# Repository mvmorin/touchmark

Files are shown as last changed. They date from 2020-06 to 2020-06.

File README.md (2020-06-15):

# Touchmark
One-piece split, staggered column 40% keyboard. First prototyped on, and inspired by, the [Signum 3.0](http://troyfletcher.net/keyboard_sales.html#signum_30). Low profile and case-less yet still robust enough for travel. Designed in KiCad with symbols and footprints from [keyboard-parts](https://github.com/mvmorin/keyboard-parts) library.

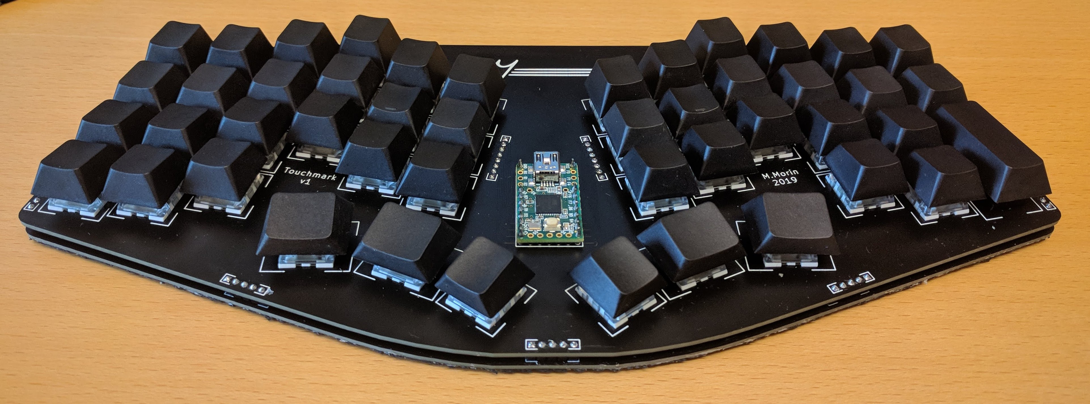
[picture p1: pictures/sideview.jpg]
sideview

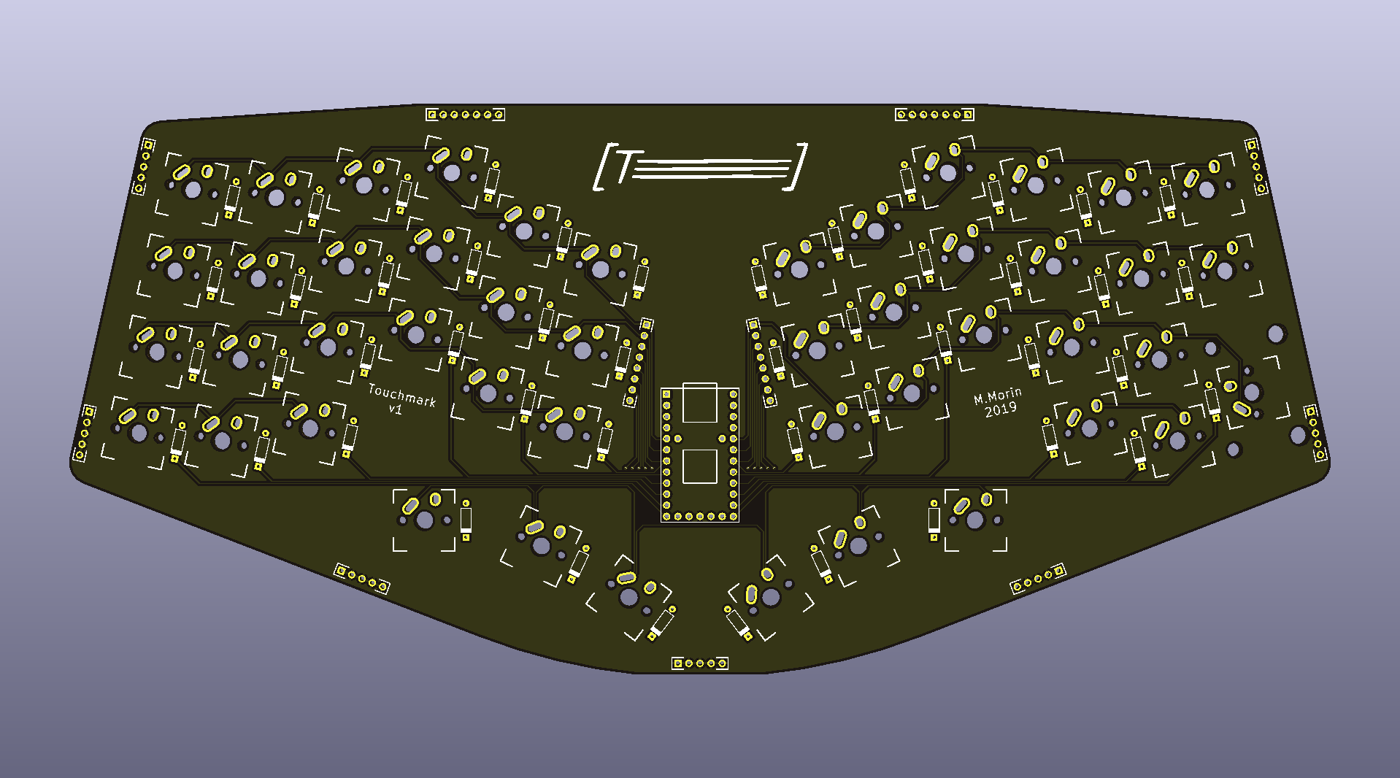
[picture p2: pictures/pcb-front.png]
pcb-front


# Features
* Low profile and case-less.
* Standard 4x12 layout.
* Teensy 2.0 and Pro-Micro compatible.
* Full PCB design, including backplate.
* Dedicated MX and Alps plates.
* Flat bottom makes it possible to use it directly on top of a laptop keyboard.

# Construction
The PCB and plate are connected via the switches and standard 2.54 mm pin headers. The Teensy/ProMicro is mounted on the plate itself (or on the base PCB if no plate is used). Only through-hole soldering is necessary and all components are placed on the top of the PCB, leaving the bottom of the keyboard flat. It is recommended to cover the bottom with some soft rubber-like material, I glued on some black shelf liner. It is of course possible to use small rubber feet instead, but this will leave the PCB exposed. It also makes it harder to use on top of a laptop keyboard since the bottom then isn't completely flat.

# PCB Files
The gerber-files for the latest version of the base PCB and the plates are found in the *gerber* directory. For instructions on how to order, see the following [40percent.club](http://www.40percent.club/2017/03/ordering-pcb.html) post. However, please read the **Known Issues** section below and be aware that the tolerances of PCB milling can be large.

# Known Issues
* Alps cutouts are a little tight. About 60% of the cutouts in the test print needed filing.
* Cherry stabilizer cutout are tight but usable.

# Future Updates
Things I'm currently thinking about changing, but who knows when...
* Change from row-high to row-low matrix for easier matrix scan in [tmk](https://github.com/tmk/tmk_keyboard) and to avoid turning on the LED when pressing column 12 keys.
* Increased stagger for pinky keys.
* Change split angle, currently slightly uncomfortable for me. The change of pinky-stagger will probably require a change to the split.
* Remove unused keys on bottom row (2,3,10,11).
* Move thumb clusters up.

# Licenses


This project is released under the [Creative Commons CC-BY-SA 4.0](https://creativecommons.org/licenses/by-sa/4.0/legalcode) license, Copyright (c) Martin Morin 2020.
Some footprints and symbols are based on parts from the [KiCad libraries](https://kicad-pcb.org/libraries/), released under the same [CC-BY-SA 4.0](https://creativecommons.org/licenses/by-sa/4.0/legalcode) license.

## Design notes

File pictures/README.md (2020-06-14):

# Pictures and Renders
sideview
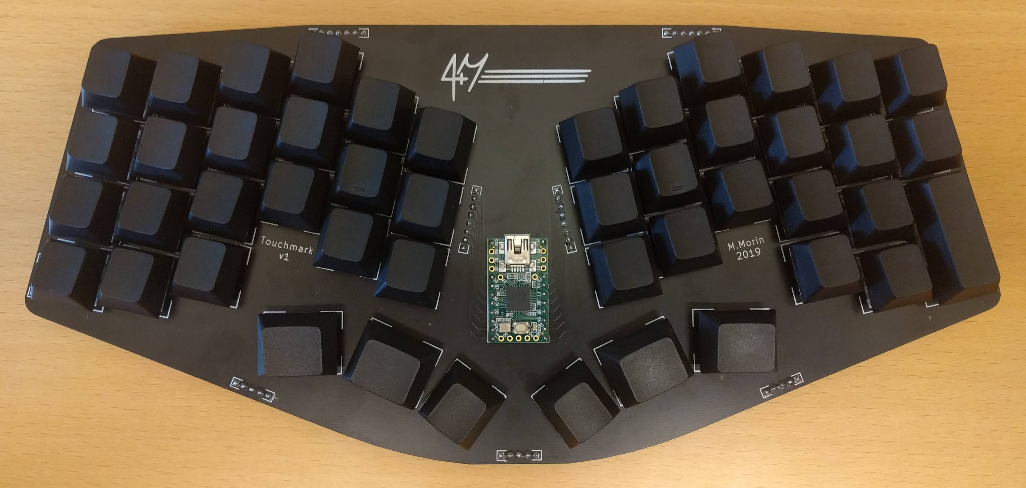
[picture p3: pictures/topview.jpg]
topview

## PCB Front and Back
pcb-front
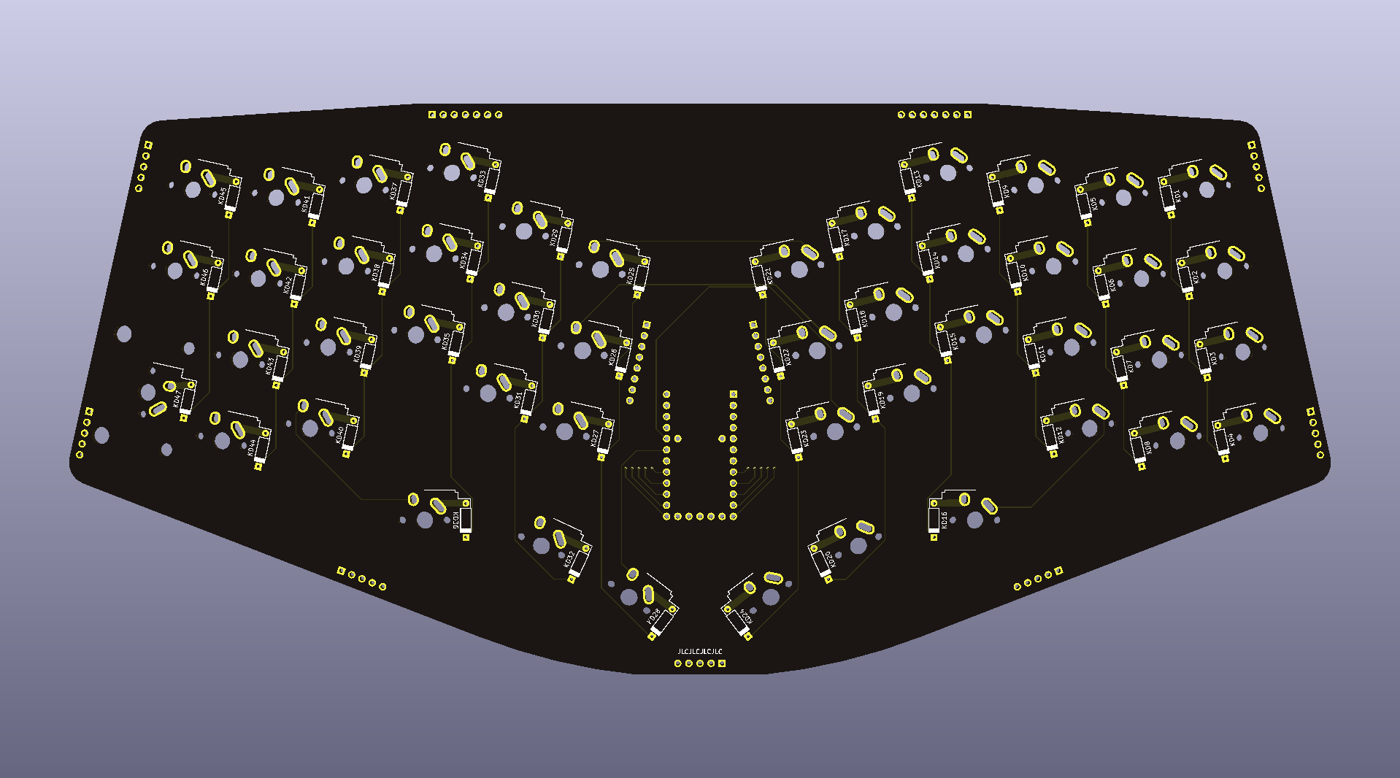
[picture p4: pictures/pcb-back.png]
pcb-back

## MX Plate
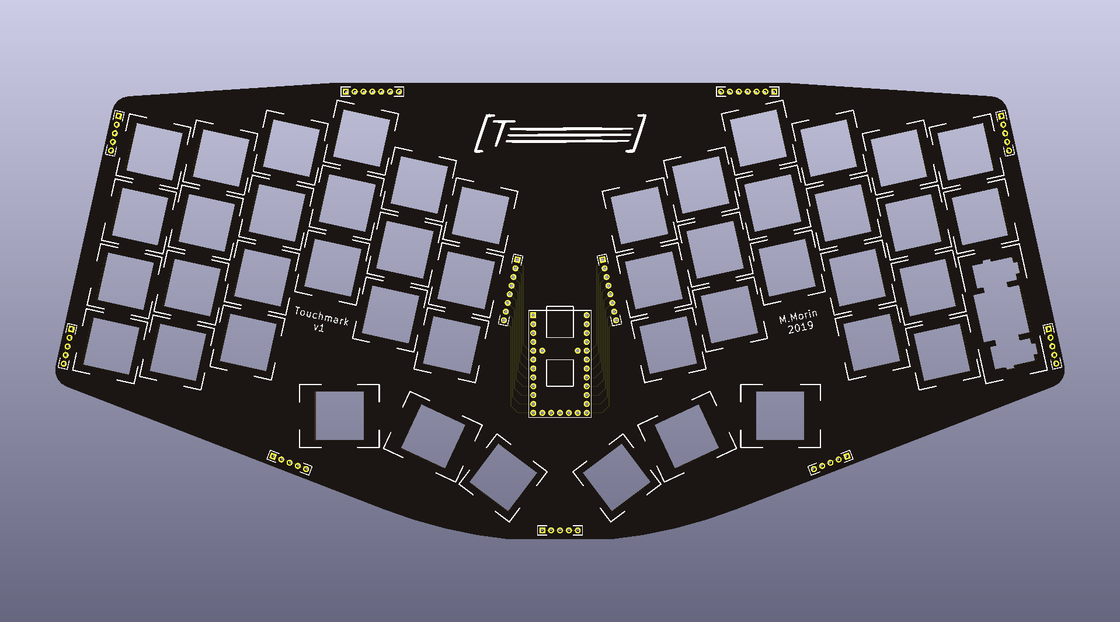
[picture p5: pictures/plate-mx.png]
plate-mx

## Alps Plate
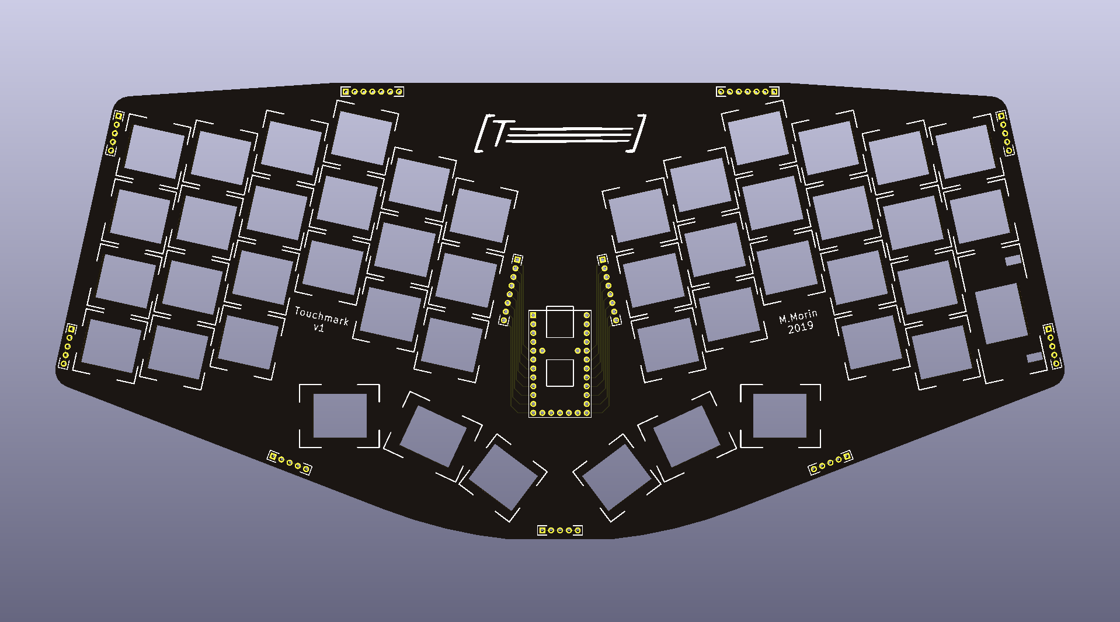
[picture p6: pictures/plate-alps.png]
plate-alps


Note the change of logo since the test print.

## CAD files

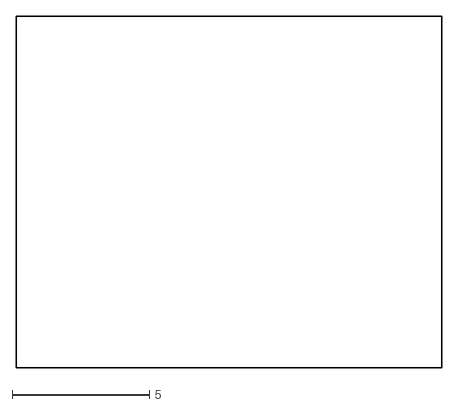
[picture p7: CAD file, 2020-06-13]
keyboard-parts/plate-cutouts/alps_cutout.dxf
15.5 x 12.8

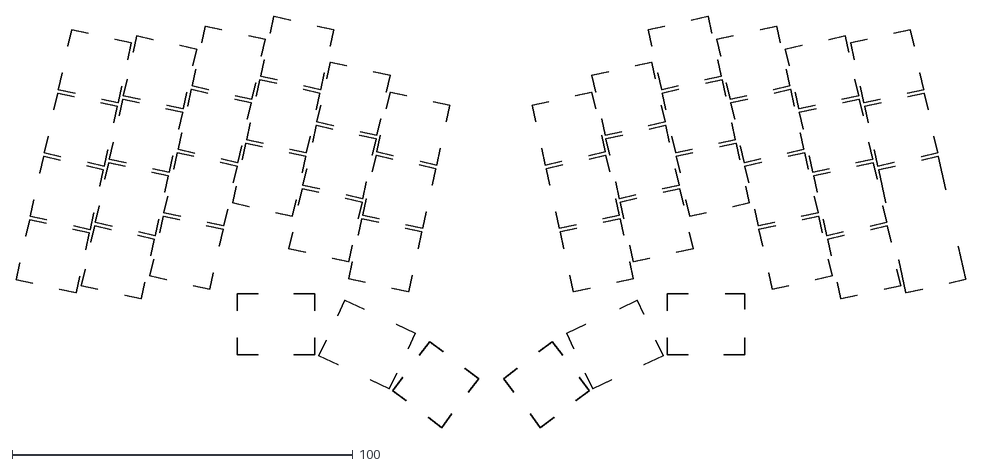
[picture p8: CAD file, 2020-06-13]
plate/outlines/plate-silk.dxf
278.8 x 120.7

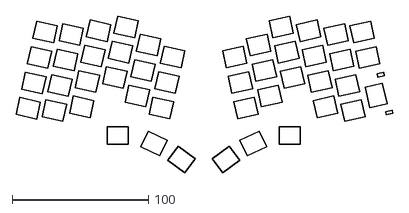
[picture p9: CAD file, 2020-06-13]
plate/outlines/alps-cutouts.dxf
276.5 x 115.1

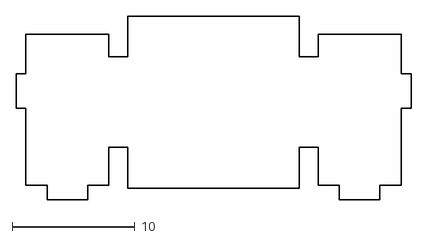
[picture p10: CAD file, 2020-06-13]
keyboard-parts/plate-cutouts/mx_cutout_stab.dxf
32.2 x 15.0

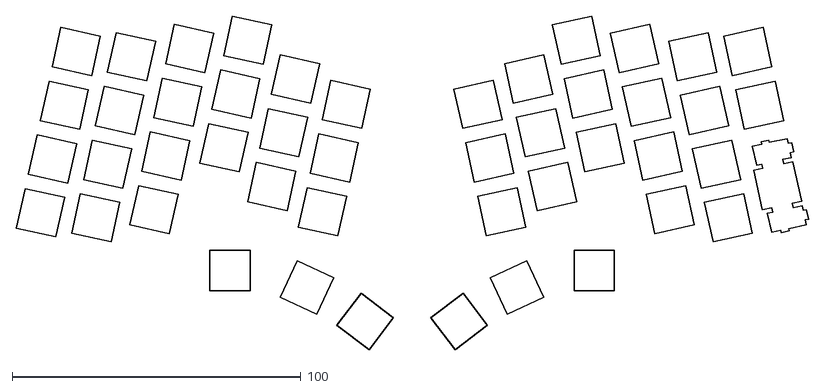
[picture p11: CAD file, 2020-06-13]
plate/outlines/mx-cutouts.dxf
274.4 x 115.5

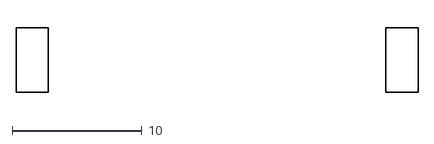
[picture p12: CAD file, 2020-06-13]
keyboard-parts/plate-cutouts/alps_stab.dxf
31.0 x 5.00

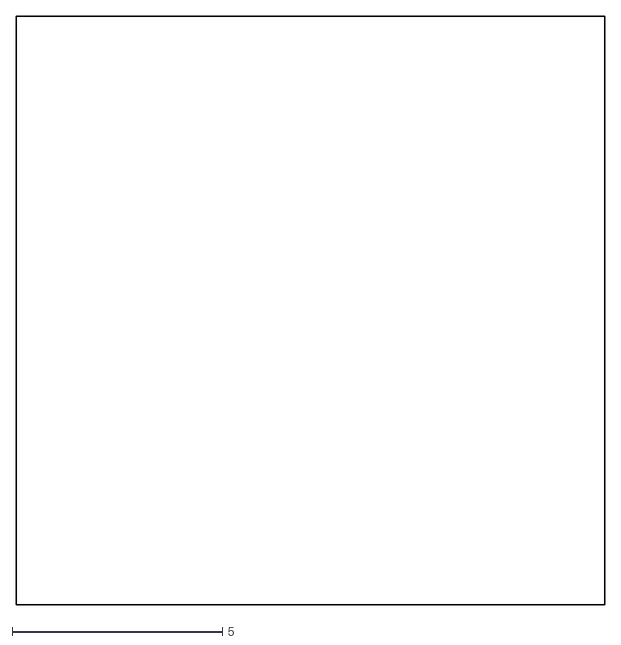
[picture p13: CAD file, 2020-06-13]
keyboard-parts/plate-cutouts/mx_cutout.dxf
14.0 x 14.0

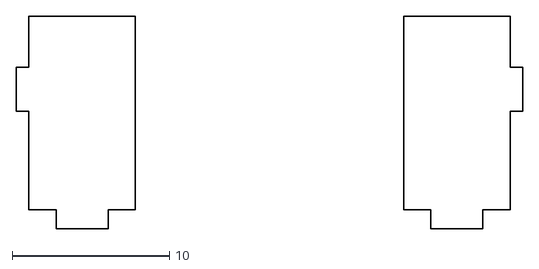
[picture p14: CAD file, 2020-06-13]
keyboard-parts/plate-cutouts/mx_stab.dxf
32.2 x 13.5

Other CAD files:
board-outline/boardoutline.FCStd
keyboard-parts/plate-cutouts/plate_cutouts.FCStd
board-outline/boardoutline.dxf

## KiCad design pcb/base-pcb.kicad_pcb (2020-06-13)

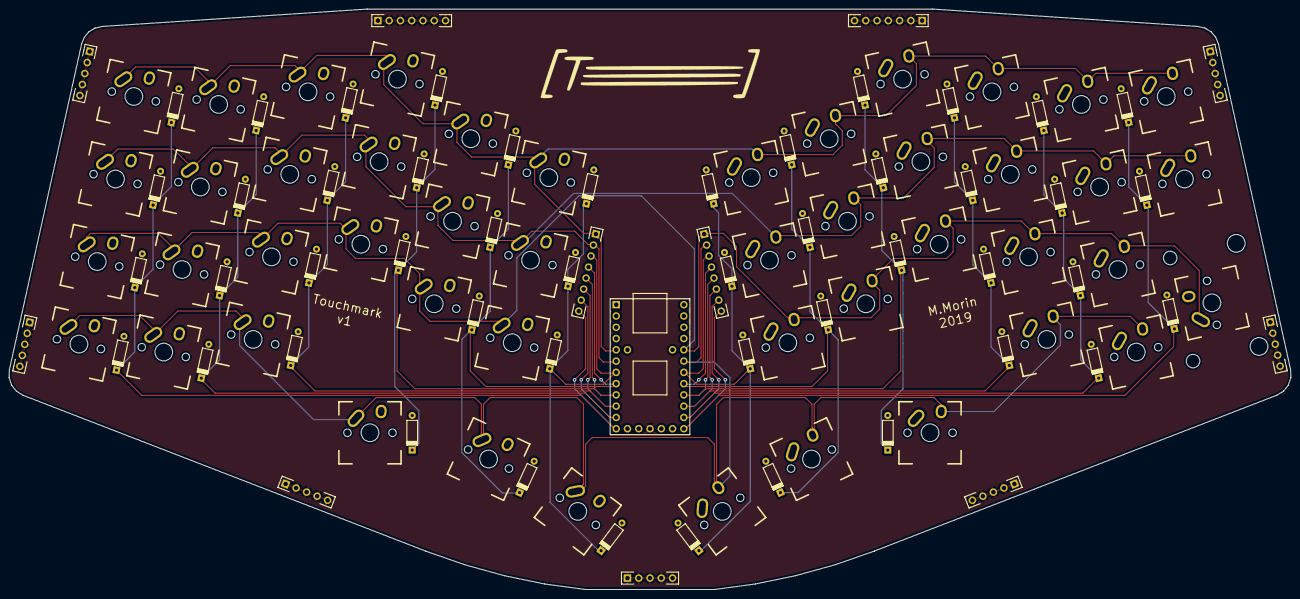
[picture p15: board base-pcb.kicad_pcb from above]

Board: 2 copper layers, 288.8 x 130.8 mm, 59 parts (0 on the bottom side), 17 nets.

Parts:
J1, J2: Conn_01x08; header_1x08_2.54mm
J3, J5: Conn_01x07; header_1x07_2.54mm
J4, J6, J7, J8, J9, J10, J11: Conn_01x05; header_1x05_2.54mm
KD1, KD2, KD3, KD4, KD5, KD6, KD7, KD8, KD9, KD10, KD11, KD12, KD13, KD14, KD15, KD17, KD18, KD19, KD21, KD22, KD23, KD24: switch-w-diode; mxalps_w_diode_R_100U
KD16, KD20: switch-w-diode; mxalps_w_diode_R_125U
KD25, KD26, KD27, KD28, KD29, KD30, KD31, KD33, KD34, KD35, KD37, KD38, KD39, KD40, KD41, KD42, KD43, KD44, KD45, KD46: switch-w-diode; mxalps_w_diode_L_100U
KD32, KD36: switch-w-diode; mxalps_w_diode_L_125U
KD47: switch-w-diode; mxalps_w_diode_200U
U1: teensy-2.0; teensy2.0

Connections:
/C0: J1.8, KD1.2, KD2.2, KD3.2, KD4.2, U1.12
/C1: J1.7, KD5.2, KD6.2, KD7.2, KD8.2, U1.11
/C2: J1.6, KD9.2, KD10.2, KD11.2, KD12.2, U1.10
/C3: J1.5, KD13.2, KD14.2, KD15.2, KD16.2, U1.9
/C4: J1.4, KD17.2, KD18.2, KD19.2, KD20.2, U1.8
/C5: J1.3, KD21.2, KD22.2, KD23.2, KD24.2, U1.7
/C6: J2.3, KD25.2, KD26.2, KD27.2, KD28.2, U1.23
/C7: J2.4, KD29.2, KD30.2, KD31.2, KD32.2, U1.22
/C8: J2.5, KD33.2, KD34.2, KD35.2, KD36.2, U1.21
/C9: J2.6, KD37.2, KD38.2, KD39.2, KD40.2, U1.20
/C10: J2.7, KD41.2, KD42.2, KD43.2, KD44.2, U1.19
/C11: J2.8, KD45.2, KD46.2, KD47.2, U1.18
/R0: J1.1, KD1.1, KD5.1, KD9.1, KD13.1, KD17.1, KD21.1, KD25.1, KD29.1, KD33.1, KD37.1, KD41.1, KD45.1, U1.5
/R1: J1.2, KD2.1, KD6.1, KD10.1, KD14.1, KD18.1, KD22.1, KD26.1, KD30.1, KD34.1, KD38.1, KD42.1, KD46.1, U1.6
/R2: J2.1, KD3.1, KD7.1, KD11.1, KD15.1, KD19.1, KD23.1, KD27.1, KD31.1, KD35.1, KD39.1, KD43.1, KD47.1, U1.25
/R3: J2.2, KD4.1, KD8.1, KD12.1, KD16.1, KD20.1, KD24.1, KD28.1, KD32.1, KD36.1, KD40.1, KD44.1, U1.24
GND: J3.1, J3.2, J3.3, J3.4, J3.5, J3.6, J3.7, J4.1, J4.2, J4.3, J4.4, J4.5, J5.1, J5.2, J5.3, J5.4, J5.5, J5.6, J5.7, J6.1, J6.2, J6.3, J6.4, J6.5, J7.1, J7.2, J7.3, J7.4, J7.5, J8.1, J8.2, J8.3, J8.4, J8.5, J9.1, J9.2, J9.3, J9.4, J9.5, J10.1, J10.2, J10.3, J10.4, J10.5, J11.1, J11.2, J11.3, J11.4, J11.5, U1.15

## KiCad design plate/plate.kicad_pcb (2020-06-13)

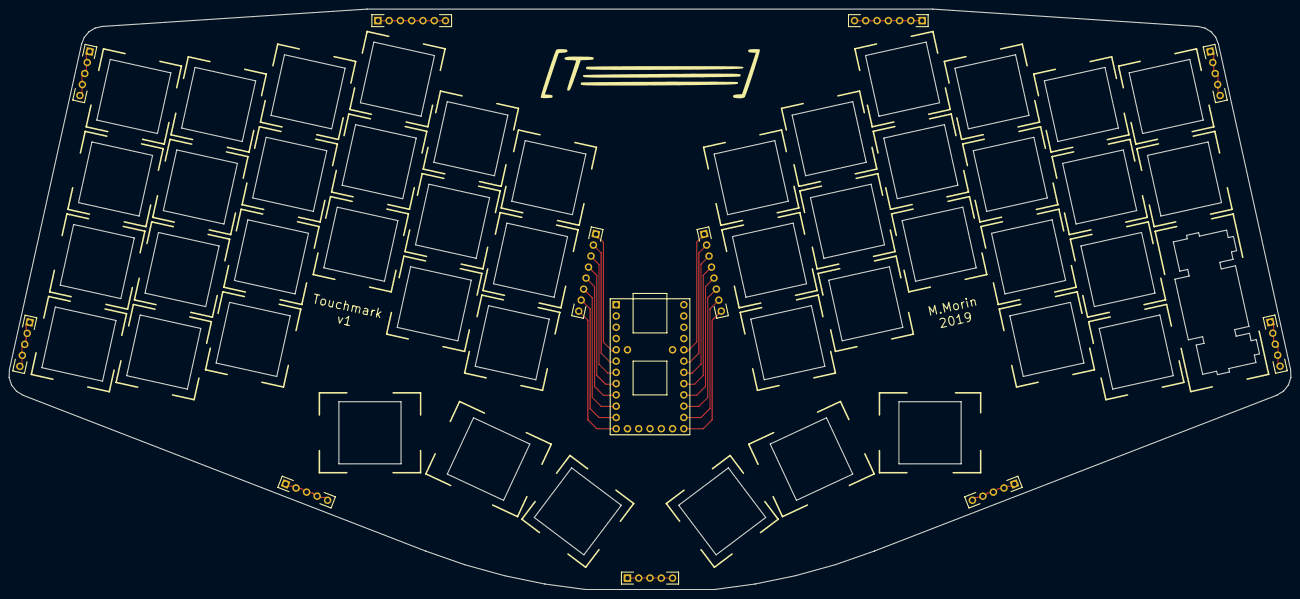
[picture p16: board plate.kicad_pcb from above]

Board: 2 copper layers, 288.8 x 130.8 mm, 12 parts (0 on the bottom side), 25 nets.

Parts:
J1, J2: Conn_01x08; header_1x08_2.54mm
J3, J5: Conn_01x07; header_1x07_2.54mm
J4, J6, J7, J8, J9, J10, J11: Conn_01x05; header_1x05_2.54mm
U1: teensy-2.0; teensy2.0

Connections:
unnamed: J1.1, U1.5
unnamed: J1.2, U1.6
unnamed: J1.3, U1.7
unnamed: J1.4, U1.8
unnamed: J1.5, U1.9
unnamed: J1.6, U1.10
unnamed: J1.7, U1.11
unnamed: J1.8, U1.12
unnamed: J2.1, U1.25
unnamed: J2.2, U1.24
unnamed: J2.3, U1.23
unnamed: J2.4, U1.22
unnamed: J2.5, U1.21
unnamed: J2.6, U1.20
unnamed: J2.7, U1.19
unnamed: J2.8, U1.18
unnamed: J3.1, J3.2, J3.3, J3.4, J3.5, J3.6, J3.7
unnamed: J4.1, J4.2, J4.3, J4.4, J4.5
unnamed: J5.1, J5.2, J5.3, J5.4, J5.5, J5.6, J5.7
unnamed: J6.1, J6.2, J6.3, J6.4, J6.5
unnamed: J7.1, J7.2, J7.3, J7.4, J7.5
unnamed: J8.1, J8.2, J8.3, J8.4, J8.5
unnamed: J9.1, J9.2, J9.3, J9.4, J9.5
unnamed: J10.1, J10.2, J10.3, J10.4, J10.5
unnamed: J11.1, J11.2, J11.3, J11.4, J11.5

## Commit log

2020-06-13 Add files, library still missing
    [alps-cutouts.dxf, base-pcb.kicad_pcb, base-pcb.sch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]
2020-06-13 Squashed 'keyboard-parts/' content from commit 33f5a16
    git-subtree-dir: keyboard-parts
    git-subtree-split: 33f5a16573515b2b95f2385123d03d383fe1608f
    [alps_cutout.dxf, alps_stab.dxf, mx_cutout.dxf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]
